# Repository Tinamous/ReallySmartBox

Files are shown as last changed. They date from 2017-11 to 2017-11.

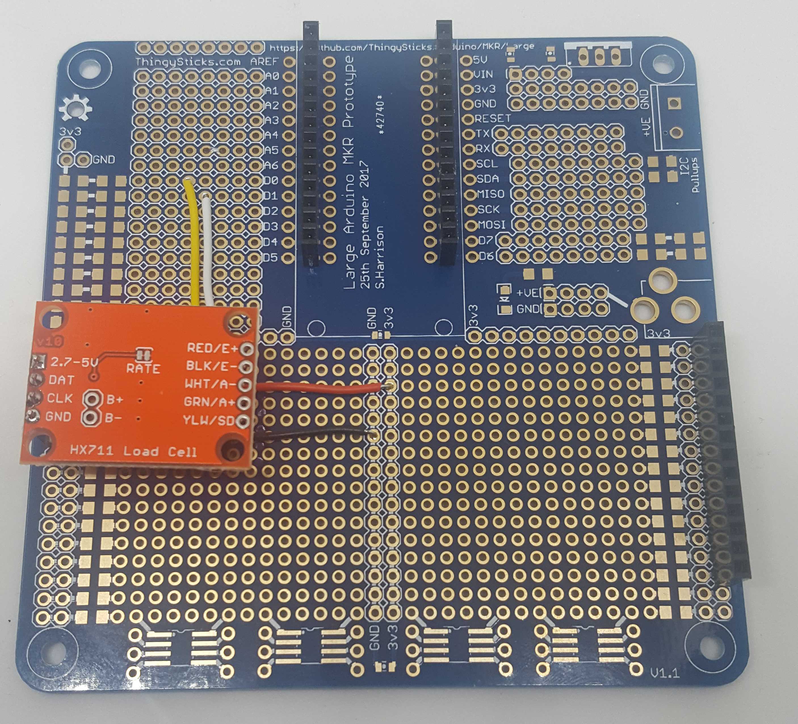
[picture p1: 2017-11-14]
Images/LoadCellWiring-2.jpg

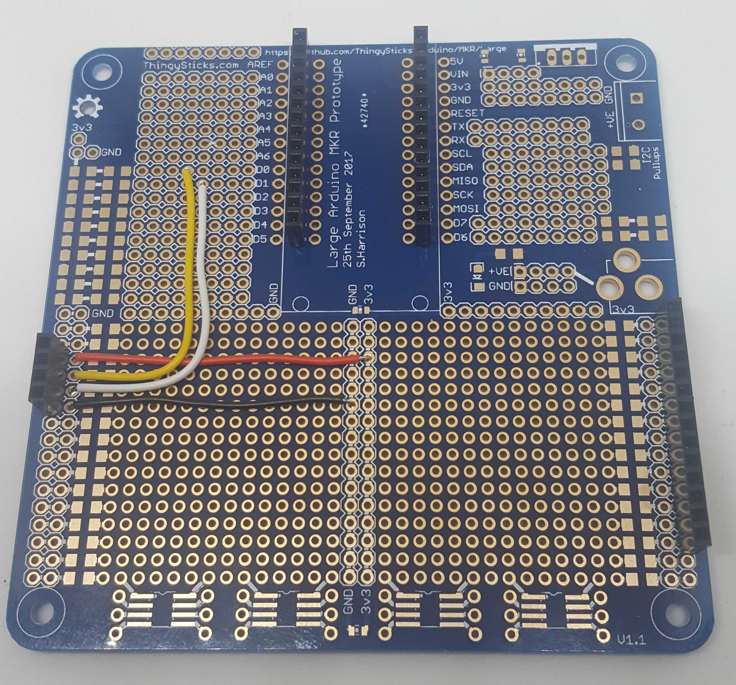
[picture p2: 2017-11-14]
Images/LoadCellWiring-1.jpg

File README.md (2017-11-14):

Really Smart Box 
==================================

Stock managment is difficult. This project aims to reduce the overhead and guess work in stock control of day to day items that are easily overlooked and time consuming to keep track of re-ordering.

Constructed of two acrylic sheets cut to fit inside a Really Useful Box (19XL) with two load cells inbetween to sense the weight and a BME 280 to monitor temperarure and humidity. Uses an Arduino Sigfox MKR FOX 1200 to read the sensors and push the measured values out via the Sigfox network.

Really Smart Box Solution:
-----------------

* Uses a regular 'Really Useful Box' for storage.
* A drop in system for the box so very little overhead is needed.
* Independant
** Low power. You don't want your storage solution having to have a power pack.
** No WiFi or client internet set-up. Many companies won't allow "gadgets" an internet connection

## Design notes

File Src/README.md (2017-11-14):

# Firmware

## Arduino Set-up

Add the following libraries:

* HX711 library: https://github.com/bogde/HX711
* Adafruit Sensor: https://github.com/adafruit/Adafruit_Sensor
* Adafruit BME280: https://github.com/adafruit/Adafruit_BME280_Library

Download as zip, use Sketch->Include Library->Add .zip file.

Then again, Sketct->Include Library->HX711-master (from the contributed libraries)

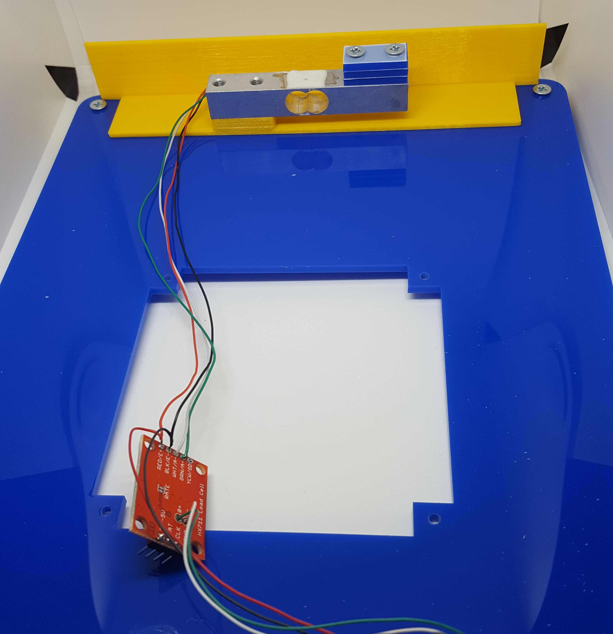
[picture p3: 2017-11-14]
Images/ElectronicsHole.jpg

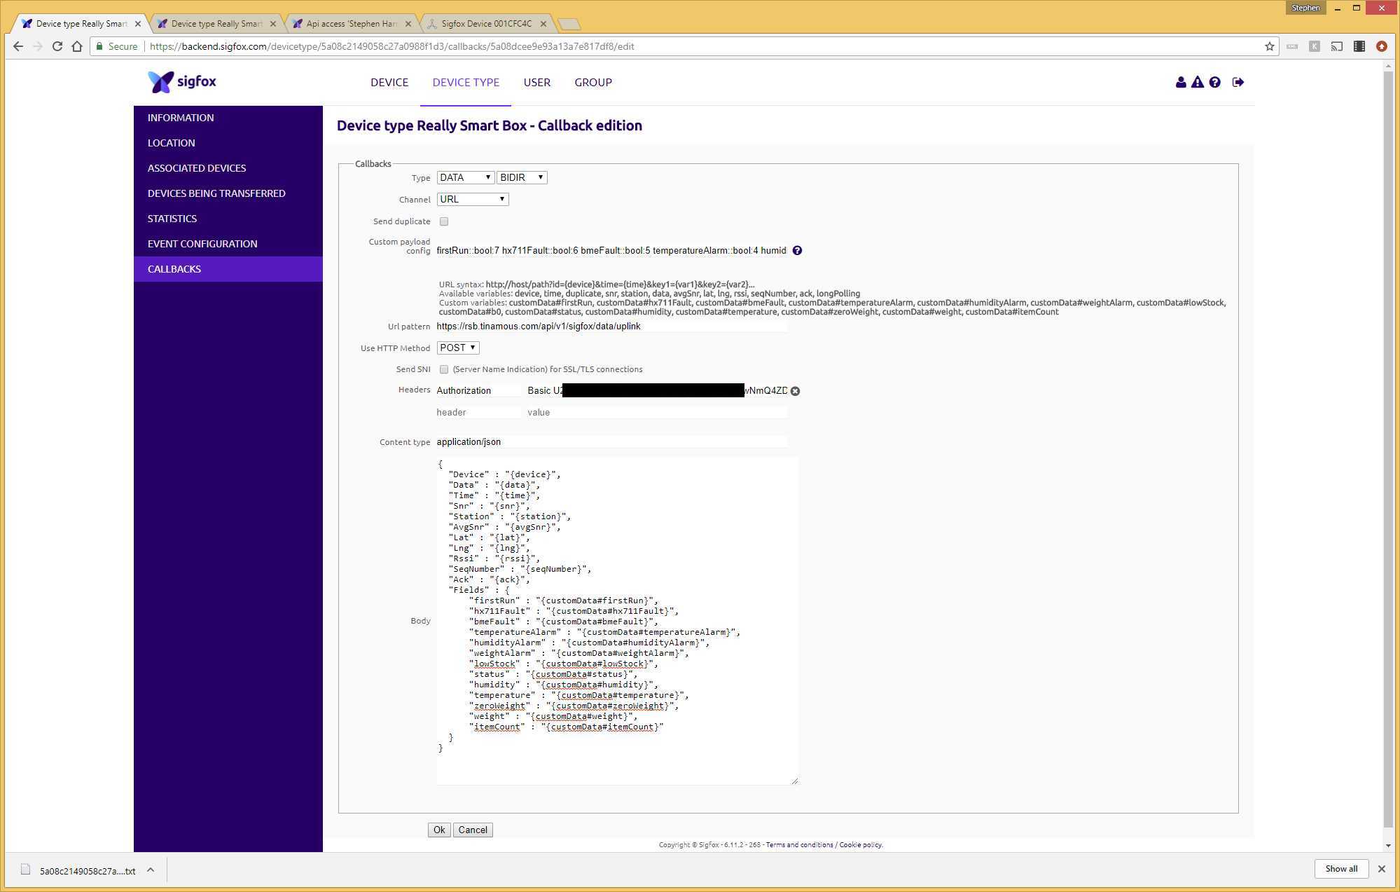
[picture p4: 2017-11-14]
Images/Callback2.jpg

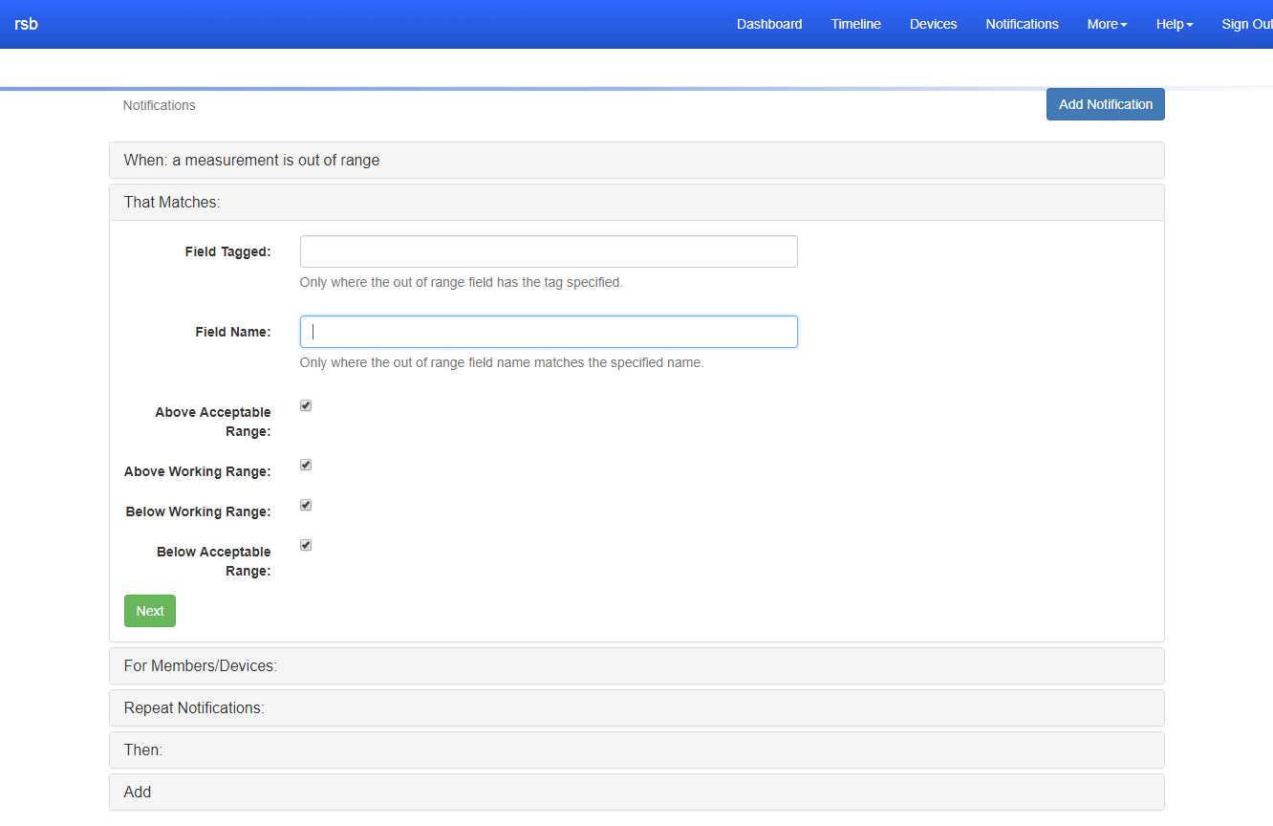
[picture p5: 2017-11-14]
Images/Notification2.jpg

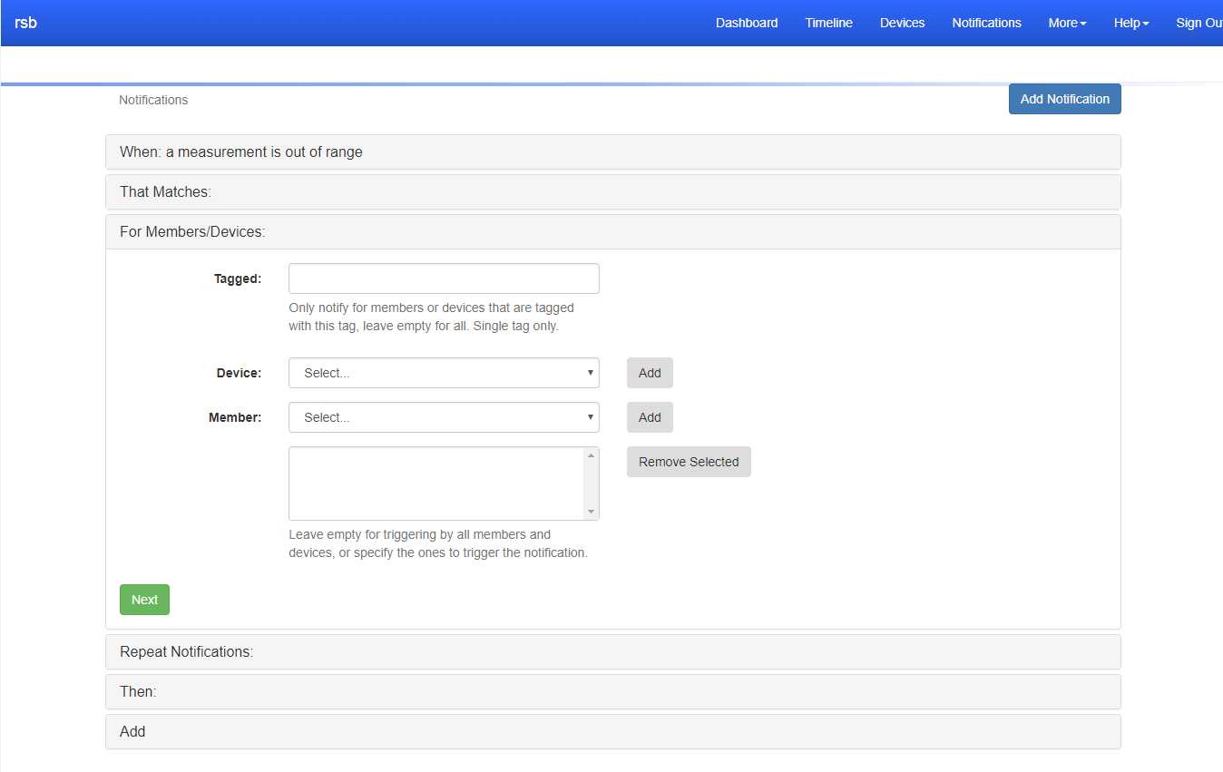
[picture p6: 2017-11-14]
Images/Notification3.jpg

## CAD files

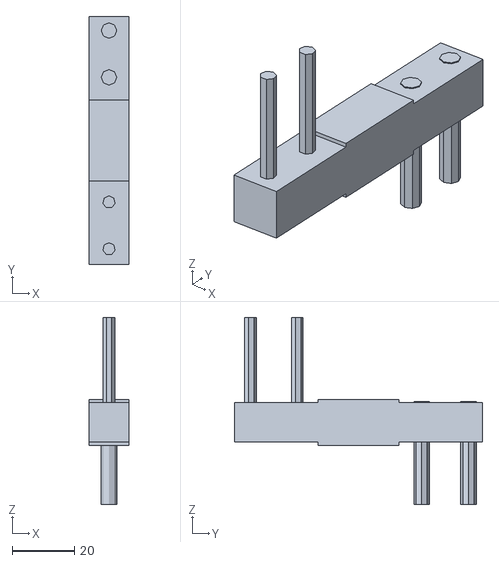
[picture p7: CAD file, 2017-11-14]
3D Printing/Extra/LoadCellModel.stl
12.8 x 79.5 x 60.0

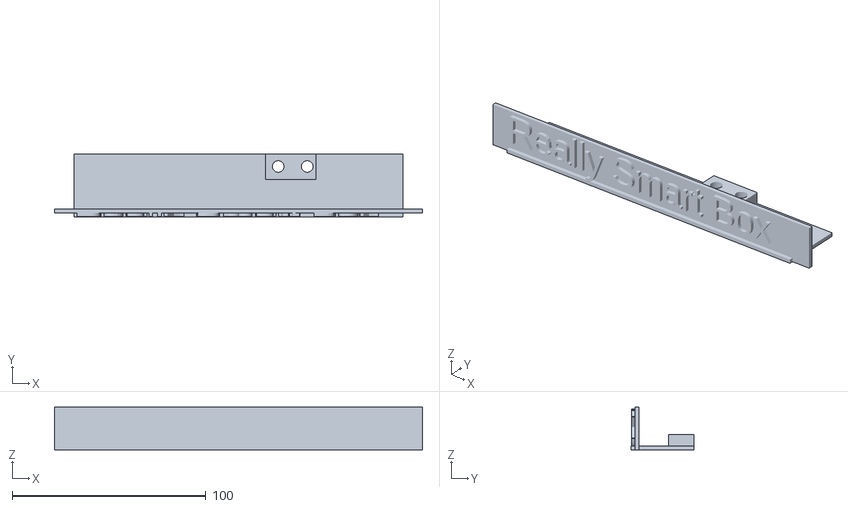
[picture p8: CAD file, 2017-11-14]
3D Printing/LoadCellBase.stl
190.0 x 32.4 x 22.0

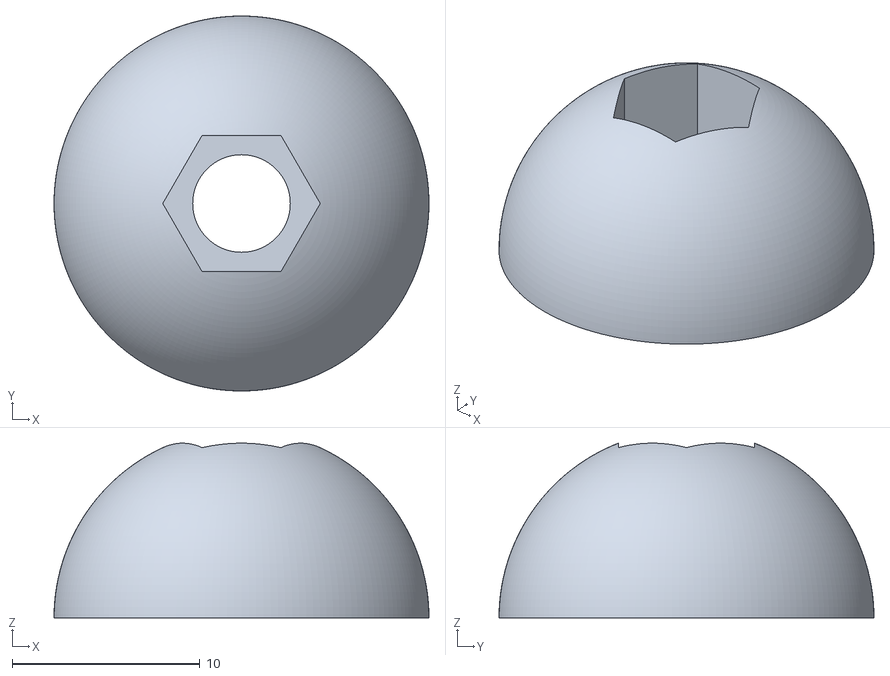
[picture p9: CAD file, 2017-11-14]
3D Printing/Foot.stl
20.0 x 20.0 x 9.31

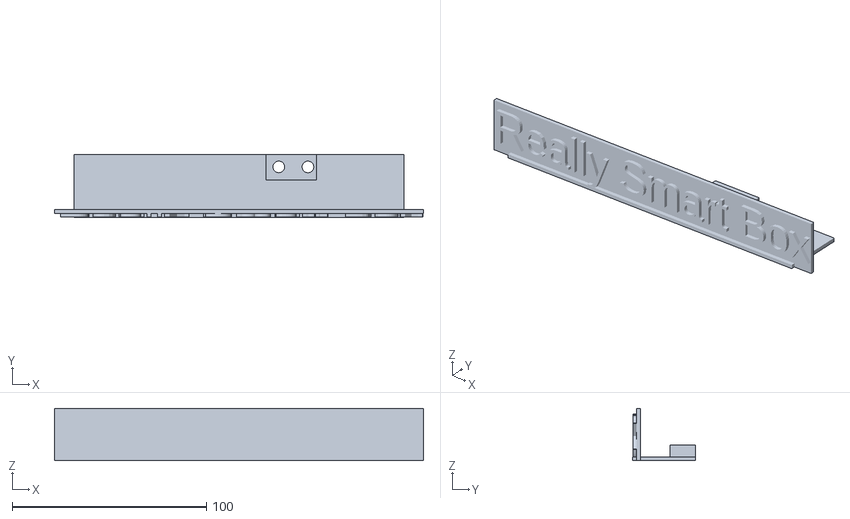
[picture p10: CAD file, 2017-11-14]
3D Printing/LoadCellBase-tall.stl
190.0 x 32.4 x 27.0

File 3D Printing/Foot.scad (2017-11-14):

$fn=160;
d=20;

difference() {
    union() {
        sphere (d=d);
    }
    union() {
        translate([-d/2, -d/2, -d]) {
            cube(d);
        }
        translate([0,0,-0.01]) {
            cylinder(d=5.8, h=d/2+0.01);
        }
        
        translate([0,0,4]) {
            #cylinder(d=8.4, h=d/2+0.01,$fn=6);
        }
    }
}

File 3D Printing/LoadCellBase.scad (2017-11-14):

// Sits between the base sheet and the load cell to raise the cell slightly and provide a side on branding message :-)


paddingHeight = 8; // 8mm max for 3mm acrylic with M5x12
loadCellDepth = 12.75;
// Depth is 26mm (offset of screws from front of base panel)
// plus the other half of the load cell
blockDepth =  26 + (loadCellDepth/2); // loadCellDepth + 2 + 6; // 13mm load cell, 6mm riser block depth and 2mm space

// Total length of the load cell padding.
//overallWidth = 120; //
overallWidth = 190; //

// Load cell first hole is 70mm in from the edge. - not a drilled hole.
// Load acual cell first hole is 126.2mm in from the edge.
// Load cell runs form 65mm to 145mm (80mm).

// We are 20mm wither side of the load cell.

rotate([0,0,-90]) {
    translate([-26,68.5+35,8]) {
    
       %import("./Extra/LoadCellModel.stl");
    }
}


difference() {
    union() {
        // Basic floor point for the thing.
        translate([10,0,0]) {
            cube([overallWidth-20, blockDepth, 2]);
        }
        
        // Front riser for text
        // TODO: Make height dynamic based on paddingHeight
        translate([0,2,0]) {
            cube([overallWidth, 2, 27]);
        }
        
        translate([1,2.1,6]) {
            rotate([90,0,0]) {
                linear_extrude(2) {
                    text("Really Smart Box", size=18);
                }
            }
        }
        
        // Padder is 26mm wide
        // 20mm padding either end of the section.
        translate([overallWidth - 81,blockDepth-13,0]) {
            // 6mm riser block with 2mm space
            #cube([26,13, paddingHeight]);
        }
    }
    union() {
        // Hole is 26mm from front edge of panel
        translate([overallWidth - 81 +6.5, 26 , -0.1]) {
            //translate([2, blockDepth, -0.1]) {
            #cylinder(d=6, h=paddingHeight+0.2, $fn=60);
            
            // 15mm gap between holes
            translate([15.0, 0 ,0]) {
                #cylinder(d=6, h=paddingHeight+0.2, $fn=60);
            }
        }
        
        // Hole for an LED
        translate([overallWidth/2, 3 ,22/2]) {
            rotate([90,0,0]) {
               // #cylinder(d=5.2, h=paddingHeight+0.2, $fn=60);
            }
        }
    }
}

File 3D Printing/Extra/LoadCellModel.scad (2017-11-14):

loadcellHeight = 12.75;
loadcellWidth = 12.75;
loadcellLength = 79.5;

module loadCell() {  
            
    // Bolts holes:
    // M4: 5.0
    // M4: 20.0
    // M5: 60.0
    // M5: 75.0
    // Center go from 26.75 to 52.75
    difference() {
        union() {
            cube([loadcellLength, loadcellWidth, loadcellHeight]);
            
            // strain gauge placement + goo
            translate([(loadcellLength-26)/2,0,loadcellHeight]) {
                cube([26,loadcellWidth,1]);
            }
            translate([(loadcellLength-26)/2,0,-1]) {
                cube([26,loadcellWidth,1]);
            }
            
            // Project bolts up (M4's going up)
            translate([5.0, (12.75/2),0]) {
                // Bigger top connector holes
                // to help align with top when visual testing
                cylinder(d=4, h=40);
            }
            translate([20, (12.75/2),0]) {
                cylinder(d=4, h=40);
            }
            
            // Project bolts down (M5's going down)
            translate([60, (12.75/2),-20]) {
                cylinder(d=5, h=33);
            }
            translate([75, (12.75/2),-20]) {
                cylinder(d=5, h=33);
            }
        }
        union() {
            translate([5.0, (12.75/2),0]) {
                // Bigger top connector holes
                // to help align with top when visual testing
                //#cylinder(d=4, h=40);
            }
            translate([20, (12.75/2),0]) {
                //#cylinder(d=4, h=40);
            }
            //60
            translate([60, (12.75/2),0]) {
                //cylinder(d=4, h=13);
            }
            translate([75, (12.75/2),0]) {
                //cylinder(d=4, h=13);
            }
        }
    }
}

loadCell();

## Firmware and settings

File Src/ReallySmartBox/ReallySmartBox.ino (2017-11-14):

// Really Smart Box
// Measures the weight of the contents of a really smart box
// Made by two sheets of acrylic with 2 load cells between them 
// placed in a really smart box.
// Also includes a BME280 to measure temperature and pressure inside the box.
// Author: Stephen Harrison
// License: MIT

#include <Adafruit_BME280.h>
#include <HX711.h>
#include <SigFox.h>
#include <SigFox.h>
#include <ArduinoLowPower.h>

// --------------------------------------
// BME280 on the I2C port.
Adafruit_BME280 bme; 

// --------------------------------------
// HX711 load cell amplifier.
// 0: D0 - DOUT
// 1: D1 - CLK
// initial gain of 128.
HX711 scales(0, 1, 128);

// Arrays for load cells. Index 0 == Channel A, Index 1 == Channel B.
float gain[] = {128,32};

// Calibration factors.
// we use y = mx + c (c = offset, m = scaleFactor).
// to convert the measured value into a weight.
// Set this to the offset reported by the load cells.
// with no weight on them.
float offset[] = {0,54940}; 

// Set this to the factor computed when a weight is placed on the scale.
// Set the offset first, re-flash the arduiono for this to take effect
// place a weight on the scale and divide the raw measured value by the weight.
// using scaleFactor = measured value / weight.
float scaleFactor[] = {378.f,260.9f};

// --------------------------------------
// Sigfox

// This is the data structure we publish to Sigfox.
// Split out the bits as bool flags from the first status byte but the byte still needs to be 
// included otherwise humidity becomes the status
// firstRun::bool:7 hx711Fault::bool:6 bmeFault::bool:5 temperatureAlarm::bool:4 humidityAlarm::bool:3 weightAlarm::bool:2 lowStock::bool:1 b0::bool:0
// status::int:8 humidity::int:8 temperature::int:8 zeroWeight::int:16:little-endian weight::int:16:little-endian itemCount::int:16:little-endian
typedef struct __attribute__ ((packed)) sigfox_message {
  uint8_t status;       // status::uint:8 -> Split to 8 bits // B7 - First run, B6 - HX711 fault, B5 BME280 fault, B4 Temperature alarm, B3 - Humidity alarm, B2 - weight alarm, B1 - Low stock, B0 - spare
  int8_t humidity;      // humidity::int:8 (yes some sensors (HTU21D read -ve humidity)
  int8_t temperature;   // temperature::int:8 (no decimal places).
  int16_t zeroWeight;   // zeroWeight::int:16:little-endian 
  int16_t weight;       // weight::int:16:little-endian
  int16_t itemCount;    // itemCount::int:16:little-endian (100x actual item count to allow for 2.01 (as weight won't match exactly)
  int8_t driftCorrection;    // Drift Correction for changes in zero weight applied to the scales.
  int8_t filler;
  int8_t lastStatus;    // Last sigfox status
} SigfoxMessage;

// Time the last Sigfox message was published at
long lastPublish = 0;

// Time the last Sigfox downlink was requested.
// Allowed max 4 per day of these.
long lastDownlink = 0;

uint8_t lastSigfoxStatus = 0;

// --------------------------------------
// Application/state

// If the fist cycle (after a reset) for the measure/publish
// cycle (this is used to request a downlink message from Sigfox).
// Note that only 4 of them are allowed per day so becareful
// when deploying code.
bool isFirstCycle = true;

// Application mode
// 0: Normal
// 1: Calibration
int mode = 0;

// Which channel should be read during calibration.
int calibrate_channel = 0;

// The last average value measured for each channel.
float lastAverage[] = {0,0};

// The current weight of the contents of the box
float currentWeight = 0;

// The weight of the units the box will hold.
// Updatable via Sigfox downlink message.
float unitWeight = 238;

// Different to tare as it would be a manual
// zero'd at a set reading from scales
// This will most likely change with drift (time/temperature/etc)
// and should be set once the scale is in place but not loaded.
// Updatable via Sigfox downlink message.
float zeroWeight = 0;

bool bmeOk = true;
bool hx711Ok = true;

// Alarms and alarm ranges
float minTemperature = 5.f;
float maxTemperature = 60.f;
float minHumidity = 0.f;
float maxHumidity = 60.f;
float maxWeight = 10000; // 10kg

bool temperatureAlarm = false;
bool humidityAlarm = false;
bool weightAlarm = false;

float currentTemperature = 0;
float currentHumidity = 0;

float stockLevel = 0;
bool lowStock = false;
float minStock = 5;

// Setup the Arduino.
void setup() {
  pinMode(LED_BUILTIN, OUTPUT);

  //Initialize serial:
  Serial.begin(9600);

  // NB: The sensor I'm using (from random eBay seller)
  // does not use the default address.
  bmeOk = bme.begin(0x76);  
  if (!bmeOk) {
    Serial.println("Could not find a valid BME280 sensor!");
  } 

  // Delay for USB Serial connect and for the BME's first reading.
  delay(5000);
  Serial.println("Really Smart Box...");
  
  printHeader();
}

int delayCounter = 0;

void loop() {
  switch (mode) {
    case 0:
      measureAndPublish();
      //Sleep for 1 minutes
      // Causing problems with USB connected.
      //LowPower.sleep(1 * 60 * 1000);
      delay(60 * 1000);
      break;
    case 1:
      calibrate();
      delay(1000);
      break;
  }

  // Check for user input via the serial port.
  checkSerial();

  // measure is done on RTC timer tick (once per minute)
  delay(100);
}

void measureAndPublish() { 
  // turn the LED on to indicate measuring.
  digitalWrite(LED_BUILTIN, HIGH);   
  printBmeValues();
  measureTemperatureAndHumidity();
  measureWeight(true);

  // Weight, temperature and humidity are read every minute
  // however we only publish occasionally.
  if (shouldPublish()) {
    publishMeasurements();
  } 
  
  digitalWrite(LED_BUILTIN, LOW);  
}

// Main measurement loop. Reads the weight from the load cells
// and stores if no noise from the previous read.
void measureWeight(bool printDetails) {
   
  scales.power_up();
  delay(500);

  float delta = readDelta(printDetails);
  if (printDetails) {
    Serial.print("\t");
    Serial.print(delta, 2);
  }

  // If the delta is between -1 and 1 (i.e. no noise)
  // update the change in overall weight and units contained
  // otherwise ignore and try again later on.
  // This ensures we use only stable readings when both channels have not changed for 
  // two sets of measurements.
  if (delta < 1.f && delta > -1.f) {
    // Remember the previous measured weight so we can get a delta.
    float lastWeight = currentWeight;
    
    // Compute the weight. Take the weight of both load cells 
    // added together then subtract the zero'd weight.
    currentWeight = lastAverage[0] + lastAverage[1] - zeroWeight;

    // Compute the difference in weight of the items in the box
    // compated to the last time we had a stable reading.
    float itemsWeightDelta = currentWeight - lastWeight;

    updateStockLevels();
    
    if (printDetails) {
      Serial.print("\t");
      Serial.print("\t");
      Serial.print(currentWeight, 2);

      Serial.print("\t");
      // divide by unit weight to estimate the stock level in the box
      Serial.print(currentWeight / unitWeight, 2);

      Serial.print("\t");
      // the change in weight, (i.e. the weight if the items added)
      Serial.print(itemsWeightDelta, 2);

      Serial.print("\t");
      // divide by unit weight to estimate the units removed/added
      Serial.print(itemsWeightDelta / unitWeight, 2);
    }
  }

  checkWeightLimits();

  if (printDetails) {
    Serial.println();
  }

  // put the ADC in sleep mode and switch 
  // off the LED now we're done measuring.
  scales.power_down();                
}

void updateStockLevels() {
  stockLevel = currentWeight / unitWeight;

  // Unlike other alarms the low stock level
  // is reset if the stock is re-stocked.
  lowStock = stockLevel < minStock;
}

// Check if the current total weight
// or a single load cell weight is out of range.
void checkWeightLimits() {
  if (currentWeight > maxWeight ) {
    weightAlarm = true;
  }

  if (lastAverage[0] > (maxWeight /2)) {
    weightAlarm = true;
  }
  
  if (lastAverage[1]> (maxWeight /2)) {
    weightAlarm = true;
  }
}

// Read the difference in weight from the last 
// average to this time across both load cells.
// average value is stored in the lastAverage array.
float readDelta(bool printDetails) {
  float aDelta = readChannel(0, true);
  if (printDetails) {
    Serial.print("\t");
  }
  float bDelta = readChannel(1, true);

  return aDelta + bDelta;
}

// Read the weight from a channel. Stores the measured value in 
// the lastAverage array and retuns the delta of the measured value
// from the previous lastAverage. This allows us to know if the weight
// has changed.
// channel 0 = A
// channel 1 = B
float readChannel(int channel, bool printDetails) {
  
  // Gain:
  // Channel A supports 128 or 64. Default 128
  // Channel B supports 32
  // Select Channel B by using gain of 32.
  scales.set_gain(gain[channel]); 
  
  // HX711 library only has one set of offset/scale factors
  // which won't work for use as we use both channels and they 
  // have different gains, so each needs to have it's offset/scale set 
  // before reading the value.
  scales.set_offset(offset[channel]);
  scales.set_scale(scaleFactor[channel]);
  
  // force read to switch to gain.
  scales.read();
  scales.read();

  float singleRead = scales.get_units();
  float average = scales.get_units(10);
  float delta = average - lastAverage[channel];
  
  if (printDetails) {
    Serial.print(singleRead, 1);
    Serial.print("\t");
    Serial.print(average, 1);
    Serial.print("\t");
    Serial.print(delta, 1);
    Serial.print("\t");
  }
  lastAverage[channel] = average;
  return delta;
}

// print the header for the debug data pushed out when measuring.
void printHeader() {
  Serial.print("BME280\t\t\t\t\t");
  Serial.print("Channel A\t\t\t");
  Serial.print("Channel B\t\t\t");
  Serial.print("\t\t");
  Serial.print("Totals \t\t\t");
  Serial.println("");

  Serial.print("Temp\t");
  Serial.print("Pressure\t");
  Serial.print("Humidity\t");
  
  Serial.print("read\t");
  Serial.print("average\t");
  Serial.print("delta\t");

  Serial.print("\t");
  
  Serial.print("read\t");
  Serial.print("average\t");
  Serial.print("delta\t");

  Serial.print("\t");

  Serial.print("sum\t");
  
  Serial.print("\t");

  Serial.print("weight\t");
  Serial.print("items\t");
  Serial.print("change\t");
  Serial.print("items added");
  Serial.println("");
}

// Calibration - reads/prints selected channel values.
void calibrate() { 
  
  digitalWrite(LED_BUILTIN, HIGH);   // turn the LED on (HIGH is the voltage level)

  scales.set_gain(gain[calibrate_channel]); 
  scales.set_offset(offset[calibrate_channel]);
  scales.set_scale(scaleFactor[calibrate_channel]);
  
  // force read to switch to gain
  Serial.print("\t|CH:\t");
  Serial.print(calibrate_channel,1);
  Serial.print("\traw:\t");
  Serial.print(scales.read(),1);
  Serial.print("\t| raw:\t");
  Serial.print(scales.read(),1);
  Serial.print("\t| units:\t");
  Serial.print(scales.get_units(), 1);
  Serial.print("\t| gain:\t");
  Serial.print(gain[calibrate_channel], 1);
  Serial.print("\t| factor:\t");
  Serial.println(scaleFactor[calibrate_channel], 1);

  digitalWrite(LED_BUILTIN, LOW);
}

// check the serial port for input from a console to allow us to alter 
// the device mode etc.
void checkSerial() {
  if(Serial.available())
  {
    char instruction = Serial.read();

    switch (instruction) {
      case '0':
        calibrate_channel = 0;
        Serial.println("Channel 0 (A) Selected");
        break;
      case '1':
        calibrate_channel = 1;
        Serial.println("Channel 1 (B) Selected");
        break;
      case 'm':
        // Measurement mode
        mode = 0;
        Serial.println("Measurement Mode");
        printHeader();
        break;
      case 'c':
        // Calibration mode
        mode = 1;
        Serial.println("Calibration Mode");
        break;
      case 't':
        // Tare. Teset the scale to 0
        Serial.println("Taring");
        scales.power_up();
        delay(500);
        scales.tare(5);
        // Need to do this for each channel
        // and update our stored offset.
        Serial.println("Not properly Tared!");
        break;
      case 'h':
        printHeader();
        break;
      case 'z':
        zeroScales();
        break;  
      case 's':
        printSigfoxModelDetails();
        break;
      default:
        Serial.println("Unknown instruction. Select: 0, 1, m, c, t, h, z, or s");
        Serial.println("m - measurement mode");
        Serial.println("c - Calibration mode");
        Serial.println("0 - Channel 0 (A) Calibration");
        Serial.println("1 - Channel 1 (B) Calibration");
        Serial.println("t - Tare (scale)");
        Serial.println("z - Zero (Weight)");
        Serial.println("h - print Header");
        Serial.println("s - print Sigfox model details");
        break;
    }
  }
}

// Measure (and record) the temperature and humidity levels
// Sets alarms if out of rage (we can't use limits on Internet service side
// as the messages may only be sent a few times a day and a brief (maybe hours)
// out of range temperature/humidity could easily be missed between
// message publishing.
void measureTemperatureAndHumidity() {
  if (!bmeOk) {
    return;
  }

  currentTemperature = bme.readTemperature();
  if (currentTemperature < minTemperature) {
    temperatureAlarm = true;
  }

  if (currentTemperature > maxTemperature) {
    temperatureAlarm = true;
  }

  currentHumidity = bme.readHumidity();
  if (currentHumidity < minHumidity) {
    humidityAlarm = true;
  }

  if (currentHumidity > maxHumidity) {
    humidityAlarm = true;
  }
}

// Print the values read from the BME280 sensor
void printBmeValues() {
    //Serial.print("Temperature = ");
    Serial.print(bme.readTemperature(), 1);
    Serial.print("\t");

    Serial.print(bme.readPressure() / 100.0F, 0);
    Serial.print("\t\t");

    Serial.print(bme.readHumidity(),1);
    Serial.print("\t\t");
}

// =============================================================
// Sigfox handing
// =============================================================

// Determine if we should publish the Sigfox message.
// We may also wish to publish if the stock level has
// changed (or a significant weight level has changed)
// but we would need to be careful of exceeding the 
// 140 messages per day for a noisy system.
bool shouldPublish() {
  // Publish every 15 minutes
  // this doesn't really need to be this often
  // but whilst developing it helps keep an eye on the system.
  int messageIntervalMinutes = 15;
  
  // On first run after reset 
  // allow a 2 minute delay for the platform to be placed into 
  // the box and stabalise before doing first publish
  // which is also expected to include a check for zeroing the platform.
  if (isFirstCycle) {
    messageIntervalMinutes = 2;
    Serial.println("First cycle");
  }

  // How long ago we last publish a Sigfox message
  long millisAgo = millis() - lastPublish;

  return millisAgo > (messageIntervalMinutes * 60 * 1000);
}

// Publish our measurements (weight, temperature, humidity etc)
// to Sigfox.
void publishMeasurements() {
  Serial.println("Sending via Sigfox...");  
  bool useDownlink = shouldUseDownlink();
  if (useDownlink) {
    Serial.println("Using Sigfox downlink...");    
  }

  // stub for message which will be sent
  SigfoxMessage msg = buildMessage();

  SigFox.begin();
  SigFox.debug();
  // Wait at least 30mS after first configuration (100mS before)
  delay(100);
  // Clears all pending interrupts
  SigFox.status();
  delay(1);

  SigFox.beginPacket();
  SigFox.write((uint8_t*)&msg, 12);
  // endPacket actually sends the data.
  uint8_t statusCode = SigFox.endPacket(useDownlink);

  printSigfoxStatus(statusCode);

  // Status = 0 for a successful send, otherwise indicates
  // a failure.
  // Store when we last published a Sigfox message
  // to allow for timed message sending.
  if (statusCode == 0) { 
    resetAlarms();
  }

  // Update the last publish/downlink times
  // even if an error resonse was received to prevent
  // repeated publishing
  lastPublish = millis();
  isFirstCycle = false;

  if (useDownlink) {
      parseDownlinkData(statusCode);
      lastDownlink = lastPublish;
  }

  // Store the status value
  lastSigfoxStatus = statusCode;
  SigFox.end();
}

void printSigfoxStatus(uint8_t statusCode) {
  Serial.print("Response status code : 0x");    
  Serial.println(statusCode, HEX);    

  if (statusCode != 0) {
    Serial.print("Sigfox Status:");    
    Serial1.println(SigFox.status(SIGFOX));
    Serial1.println();
  
    Serial.print("Atmel Status:");    
    Serial1.println(SigFox.status(ATMEL));
    Serial1.println();
  }
}

// Create the message to be publish to Sigfox.
SigfoxMessage buildMessage() {
  SigfoxMessage message;

  message.status = getStatusFlags();
  message.humidity = (int8_t )currentHumidity;
  message.temperature = (int8_t)currentTemperature;
  message.zeroWeight = (int16_t)zeroWeight;   
  message.weight = (int16_t)currentWeight;       
  message.itemCount = (int16_t)(stockLevel * 100);      
  message.driftCorrection = 0; // TODO
  message.filler = 0;
  message.lastStatus = lastSigfoxStatus;

  return message;
}

// Get the status flags for the Sigfox message.
byte getStatusFlags() {
  byte status = 0;

  // B7 - First run,
  // B6 - HX711 fault 
  // B5 - BME280 fault
  // B4 - Temperature alarm
  // B3 - Humidity alarm
  // B2 - weight alarm
  // B1 - Low stock
  // B0 - spare
  
  // Upper Nibble (Charging/Battery)
  // Battery flat
  if (isFirstCycle) {
    status |= 0x80; // 1000 0000
  }

  // HX711 fault.
  // we don't have a way to check this yet.
  if (!hx711Ok) {
    status |= 0x40; // 0100 0000
  }

  // BME280 fault
  if (!bmeOk) {
    status |= 0x20; // 0010 0000
  }

  // Over/Under temperature alarm
  if (temperatureAlarm > 0) {
    status |= 0x10; // 0001 0000
  }

  // Over/Under humidity alarm
  if (humidityAlarm) {
    status |= 0x08; // 0000 1000
  }

  // Over/under? weight alarm
  if (weightAlarm) {
    status |= 0x04; // 0000 0100
  }

  // if computed stock level low.
  if (lowStock) {
    status |= 0x02; // 0000 0010
  }

  return status;
}

// Determine if we are requesting a downlink message.
bool shouldUseDownlink() {
  // When debugging uncomment this so as to not keep requesting
  // downlink 
  //return false;
  
  // On first run we want to request a downlink 
  // message to help with zero'ing and setup.
  if (isFirstCycle) {
    return true;
  }

  // How long ago we last did a downlink message.
  long millisAgo = millis() - lastDownlink;

  // try every 12 hours, this keeps us under the 
  // maximum 4 per day.
  return millisAgo > (12 * 60 * 60 * 1000);
}

// Parse downlinked data.
void parseDownlinkData(uint8_t statusMessage) {
 
  if (statusMessage > 0) {
    Serial.println("No transmission. Status: " + String(statusMessage));
    return;
  }

  // Max response size is 8 bytes
  // set-up a empty buffer to store this. (0x00 == no action for us.)
  uint8_t response[] = {0x00, 0x00, 0x00, 0x00, 0x00, 0x00, 0x00, 0x00 };

  // Expect...
  // Byte 0: Flags
  // B7: Zero scales
  // B6: Set Temperature range (ignore min/max temp if 0)
  // B5: Set Humidity range (ignore min/max humidity if 0)
  // B4: Set tolerance?
  // B3: Set ???
  // B2: Update unit weight (ignore update if 0)
  // B1: 
  // B0:
  // Byte 1: Min T
  // Byte 2: Max T
  // Byte 3: Min Humidity
  // byte 4: Max Humidity
  // byte 5: Read tolerence??? (+/- x)
  // byte 6 & 7: Unit weight

  // Parse the response packet from Sigfox
  if (SigFox.parsePacket()) {
    
    Serial.println("Response from server:");
    // Move the response into  local buffer.
    int i = 0;
    while (SigFox.available()) {
      Serial.print("0x");
      int readValue = SigFox.read();
      Serial.println(readValue, HEX);
      response[i] = (uint8_t)readValue;
      i++;
    }

    // byte 0 - flags.
    // 0b 1000 0000
    if (response[0] & 0x80 == 0x80) {
      zeroScales();
    }

    // 0b 0100 0000
    if (response[0] & 0x40 == 0x40) {
      updateTemperatureAlarm(response[1], response[2]);
    }

    // 0b 0010 0000
    if (response[0] & 0x20 == 0x20) {
      updateHumidityAlarm(response[3], response[4]);
    }

    // 0b 0000 0100
    if (response[0] & 0x04 == 0x04) {
      // Little Endian format. (ff dd -> 0xddff
      uint16_t weight = response[7] << 8 & response[6];
      updateUnitWeight(weight);
    }
  } else {
    Serial.println("No response from server");
  }
  Serial.println();
}

void printSigfoxModelDetails() {
  if (!SigFox.begin()) {
    Serial.println("Shield error or not present!");
    return;
  }
  
  // Output the ID and PAC needed to register the 
  // device at the Sigfox backend.
  String version = SigFox.SigVersion();
  String ID = SigFox.ID();
  String PAC = SigFox.PAC();

  // Display module informations
  Serial.println("MKRFox1200 Sigfox configuration");
  Serial.println("SigFox FW version " + version);
  Serial.println("ID  = " + ID);
  Serial.println("PAC = " + PAC);

  Serial.println("");

  Serial.print("Module temperature: ");
  Serial.println(SigFox.internalTemperature());

  Serial.println("Register your board on https://backend.sigfox.com/activate with provided ID and PAC");

  delay(100);

  // Send the module to the deepest sleep
  SigFox.end();
}

// =============================================================
// General helper methods
// =============================================================

// Reset the alarms after they have been published.
void resetAlarms() {
  temperatureAlarm = false;
  humidityAlarm = false;
  weightAlarm = false;
}

void zeroScales() {
  zeroWeight = lastAverage[0] + lastAverage[1];
  Serial.print("Zero'd: ");
  Serial.print(zeroWeight, 1);
  Serial.println();
}
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

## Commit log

2017-11-14 Laser cutting templates for the acrylic platform.
    Use CuttingGuige for laser cutting.
2017-11-14 Added 3D printed models.
    [Foot.scad, Foot.stl, LoadCellBase-tall.stl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]
2017-11-14 Added Arduino source code for Arduino MKR FOX 1200
